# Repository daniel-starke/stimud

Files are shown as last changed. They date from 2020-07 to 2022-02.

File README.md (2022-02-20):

STIMUD
======

The **Sti**ck **Mu**lti **D**rive makes it possible to host multiple bootable USB images in one device.  
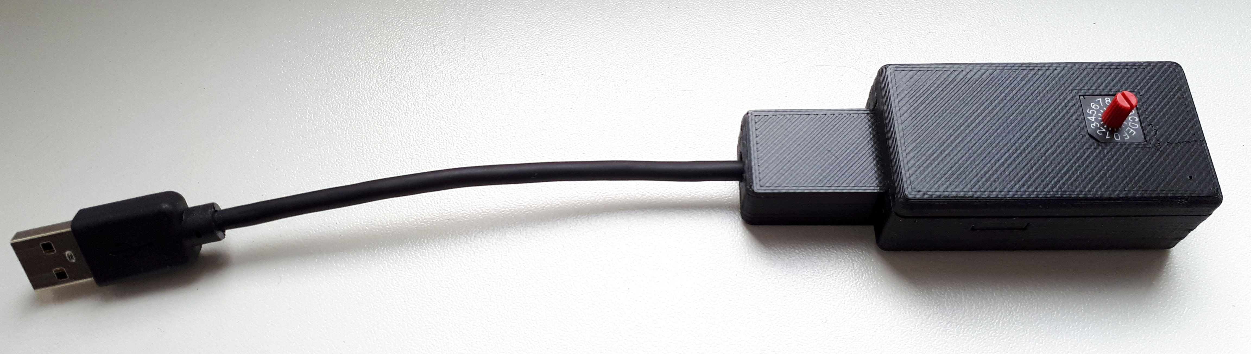
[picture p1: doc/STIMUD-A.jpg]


Features
========

- small and cheap design
- up to 16 different USB images in one device
- flexible storage capacity options by using standard microSD cards as backbone
- moderate speed: 6.36 MByte/s write, 17.2 MByte/s read ([tested](doc/h2testw-stimud.txt) with SanDisk Ultra 16GB)
- fast USB startup time of [~3 seconds](doc/startup-lz4.txt)
- as little as 0.7W energy consumption
- status and activity LED
- supported backbone file systems: FAT32, exFAT, NTFS, ext3 and ext4

Hardware Assembly
=================

STIMUD was made in three revisions. A, B and C. Each required a different level of soldering skills.  
Simple through-hole soldering skill is needed for revision A and C whereas C can be seen as improved version of A.  
Advanced SMD and through-hole soldering skills are needed to assemble revision B. Especially when using a USB-C connector.  

Required Tools
--------------

- soldering iron and lead
- 3D printer
- rasp
- glue
- microSD card reader/writer

Revision A and C
----------------

Needed parts:  
- 1x [LicheePi Zero](https://www.aliexpress.com/item/4000223515312.html)
- 1x [rotary switch with real or complementary code, 10 or 16 positions and a 3:1 or 3:3 footprint](https://lcsc.com/product-detail/Coded-Rotary-Switches_Knitter-switch_DRS4116_Knitter-switch-DRS4116_C237060.html)
- 2x [single row flat pin header with 7 pins](https://www.aliexpress.com/item/32977160718.html)
- 2x [single row flat pin socket with 7 pins](https://www.aliexpress.com/item/32977160718.html)
- 1x [micro USB cable](https://www.aliexpress.com/item/4000540452118.html)
- 1x [microSD card](https://www.aliexpress.com/item/33034672593.html)
- 1x [self adhesive 3mm thick foam pad](https://www.aliexpress.com/item/4000450236527.html)
- 1x [STIMUD PCB Rev. A](hw/switch-a/gerber) or 1x [STIMUD PCB Rev. C](hw/switch-c/gerber)
- 1x [STIMUD case](hw/switch-a/Case.FCStd)

The rotary switch and flat pin headers are soldered to the STIMUD PCB. See KiCAD project for [rev. A](hw/switch-a/switch.pro) or [rev. C](hw/switch-c/switch.pro).  
Gerber files for manufacturing at JLCPCB are provided [here](hw/switch-a/gerber) for rev. A and [here](hw/switch-c/gerber) for rev. C.  
Be sure to select 1.6mm PCB thickness or adjust the case dimensions.  
Also solder the flat pin sockets to the LicheePi Zero.  
The housing can be 3D printed via a FDM 3D printer. The needed STL files are found [here](hw/switch-a) for both revisions.  
Adjust the tolerance parameters in the [FreeCAD project](hw/switch-a/Case.FCStd) to match the used 3D printer performance.  
This step requires re-creation of the STL files for 3D printing. It is recommended to use the Mesh Design workspace in FreeCAD to adjust the quality settings before STL export.  
Be sure to print `CaseB.stl` and `ConA.stl` with support material. Some parts may need to be rasped for a proper fit afterwards.

Assembly example:  
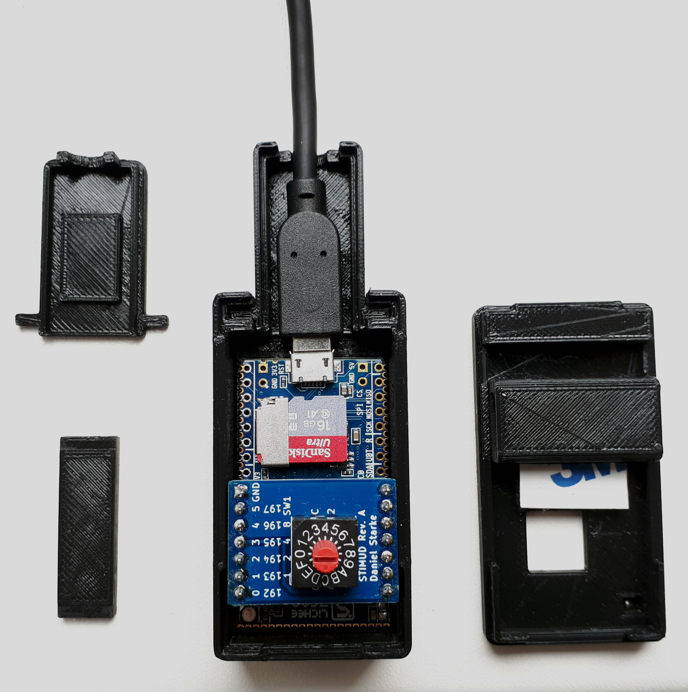
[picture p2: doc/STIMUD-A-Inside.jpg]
  
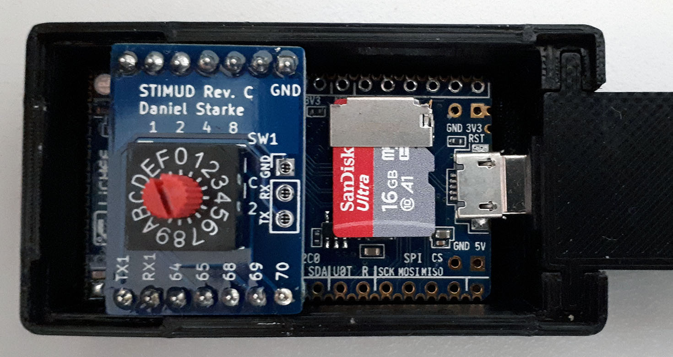
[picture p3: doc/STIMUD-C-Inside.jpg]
  


Add some glue between ConA part and USB cable for pull relief.  
It may needs a little hole for the LED light in CaseB if the used case material transparency is insufficient.  
Revision C fixes the issue in revision A, that the LED shared the same pins as the rotary switch and also adds a serial console pin header.  

**It is highly recommended to use rev. C instead of rev. A.**

Note that the serial console function for rev. C is not yet implemented.

Revision B
----------

Needed parts:  
- 1x [LicheePi Zero](https://www.aliexpress.com/item/4000223515312.html)
- 1x [vertical rotary switch with real or complementary code, 10 or 16 positions and a 4:1 footprint](https://lcsc.com/product-detail/Coded-Rotary-Switches_Knitter-switch_DRR4016_Knitter-switch-DRR4016_C237044.html)
- 2x [single row pin header with 30 pins and 1.27mm spacing](https://lcsc.com/product-detail/Pin-Header-Female-Header_BOOMELE-Boom-Precision-Elec-1-27mm-1x50P_C3408.html)
- 1x [single row pin header with 3 pins and 2.54mm spacing](https://lcsc.com/product-detail/Pin-Header-Female-Header_BOOMELE-Boom-Precision-Elec-C49257_C49257.html) (optional)
- 1x [USB-A plug](https://lcsc.com/product-detail/USB-Connectors_Jing-Extension-of-the-Electronic-Co-C9739_C9739.html) or [USB-C receptacle](https://lcsc.com/product-detail/USB-Connectors_Korean-Hroparts-Elec-TYPE-C-31-M-12_C165948.html)
- 1x [microSD card socket](https://lcsc.com/product-detail/Card-Sockets-Connectors_Korean-Hroparts-Elec-TF-01A_C91145.html)
- 1x [microSD card](https://www.aliexpress.com/item/33034672593.html)
- 2x [5.1kOhm 0603 SMD resistor](https://lcsc.com/product-detail/Chip-Resistor-Surface-Mount_UNI-ROYAL-Uniroyal-Elec-0603WAF5101T5E_C23186.html) (only in case of USB-C receptacle)
- 1x [33kOhm 0603 SMD resistor](https://lcsc.com/product-detail/Chip-Resistor-Surface-Mount_UNI-ROYAL-Uniroyal-Elec-0603WAF3302T5E_C4216.html)
- 6x [100nF 0603 SMD capacitor](https://lcsc.com/product-detail/Multilayer-Ceramic-Capacitors-MLCC-SMD-SMT_IHHEC-HOLY-STONE-ENTERPRISE-CO-LTD-C0603X104K050T_C187860.html)
- 1x [self adhesive 3mm thick foam pad](https://www.aliexpress.com/item/4000450236527.html)
- 3x [M3 nut](https://www.aliexpress.com/item/32981886856.html)
- 3x [12mm M3 screw](https://www.aliexpress.com/item/32981886856.html)
- 1x [STIMUD PCB Rev. B](hw/switch-b/gerber)
- 1x [STIMUD case](hw/switch-b/Case.FCStd)

The rotary switch, pin headers, microSD card socket, USB connector, SMD resistors and capacitors are soldered to the STIMUD PCB. The 5.1kOhm resistors are only needed for
the variant with the USB-C receptacle. See KiCAD project for [rev. B](hw/switch-b/switch.pro).  
Gerber files for manufacturing at JLCPCB are provided [here](hw/switch-b/gerber).  
Be sure to select 1.2mm PCB thickness or adjust the case dimensions.  
The LicheePi Zero is soldered directly to the pin headers previously soldered to the STIMUD PCB. Be sure to finish soldering the capacitors before attaching the LicheePi Zero.  
The housing can be 3D printed via a FDM 3D printer. The needed STL files are found [here](hw/switch-b) for the USB-A variant.  
Adjust the tolerance parameters in the [FreeCAD project](hw/switch-b/Case.FCStd) to match the used 3D printer performance.  
This step requires re-creation of the STL files for 3D printing. It is recommended to use the Mesh Design workspace in FreeCAD to adjust the quality settings before STL export.  
Everything can be printed without support material.

Assembly example:  
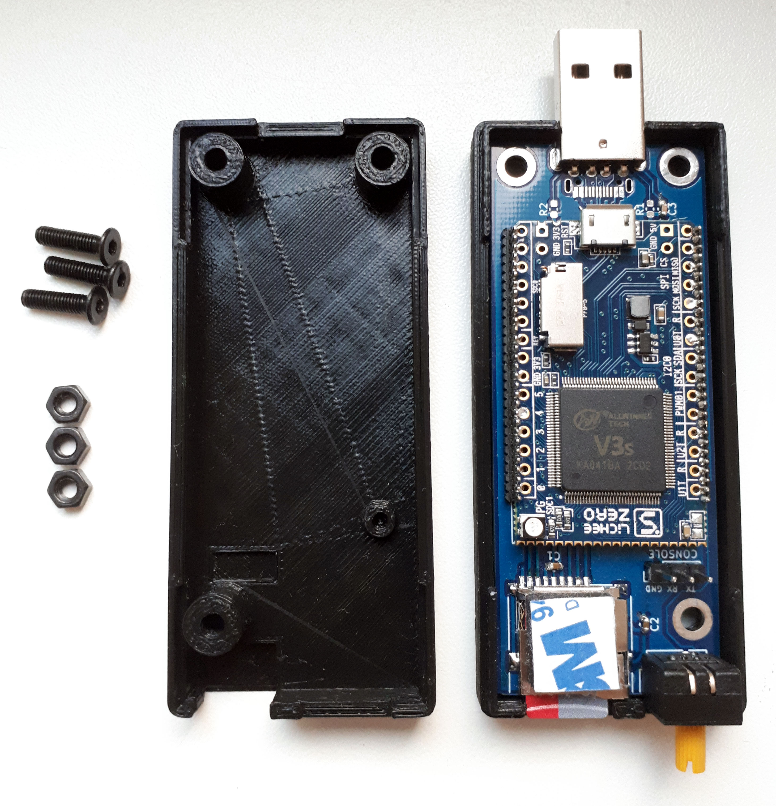
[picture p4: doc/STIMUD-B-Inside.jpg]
  
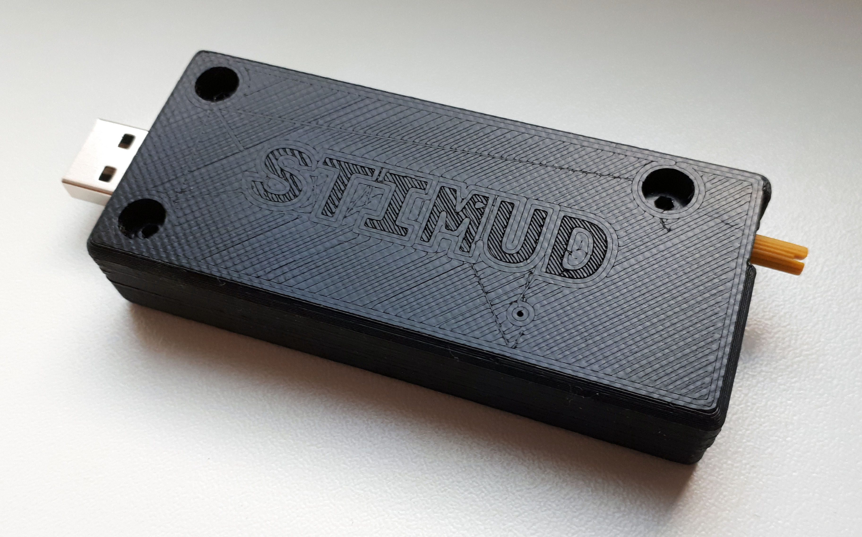
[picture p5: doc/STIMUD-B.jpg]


Attach the self adhesive foam pad on the microSD card socket to avoid unaligned insertions of microSD cards.

Note that there exists no housing for the USB-C receptacle variant yet.

**Important: Never operate the STIMUD REV B with two microSD cards at the same time! This will damage the cards and the LicheePi Zero board.**

Software Setup
==============

Build Pre-requirements
----------------------

The initial boot image can be build in Linux using the provided `build.sh` script.  
For the pre-requirements see https://buildroot.org/downloads/manual/manual.html#requirement

Build Boot Image
----------------

Execute `build.sh`. The resulting image can be found in `build/output/images/`. Additional flags can be passed to `build.sh` to control the build output.  
Use dd on Linux or [Rufus](https://rufus.ie/) on Windows to flash the microSD card.  
The partition for the sub images will be created automatically by STIMUD according to `stimud.cfg` after first start, which may take a bit longer.  
A pre-compiled image is also provided.

Configuration
-------------

Set the rotary switch to position **`F`** and adjust `stimud.cfg`.  
You can change the properties of the rotary switch coding, preferred backbone filesystem and image configurations here.  
Note that the backbone filesystem option is only used for initial format. Any of the supported filesystems can be used.  
Images can be copied as image files or created for example with the following Linux command:  

```shell
for i in 0 1 2 3 4 5 6 7 8 9 A B C D E; do dd if=/dev/zero of=$i.img bs=1048576 count=1008; mkfs -t vfat -n $i $i.img; done
```

This creates the images 0.img, 1.img, 2.img, 3.img, 4.img, 5.img, 6.img, 7.img, 8.img, 9.img, A.img, B.img, C.img, D.img and E.img in the current directory with a size of 1018MB each formatted with FAT32.  
Note that the configuration file `stimud.cfg` can be located in three locations:

1. secondary partition on the microSD card (which also includes the images)
2. primary partition on the microSD card
3. Linux kernel initfs

The priority is handled in the order given above. A missing file is replaced by the next location in the list.

Usage
=====

After successful configuration, set the rotary switch to the desired position before plugging it to the host.  
The current image can be changed at any time and will be effective on next connection to the host.  
Each image file represents a full USB storage drive image.  
Usually one position remains reserved to access the STIMUD configuration. This is position `F` by default.

Access to the internal command-line console is provided in STIMUD rev. B and C via a 3.3V TTL UART connection
with 115200 Baud, 8 data bits, no parity and 1 stop bit. The STIMUD related files are stored there in `/root`.
[Such](https://www.aliexpress.com/item/32617951363.html) an FT232R adapter module can be used for example, to connect a PC to it.

**Important: Never operate the STIMUD REV B with two microSD cards at the same time! This will damage the cards and the LicheePi Zero board.**

LED States
==========

|LED |State |Meaning
|:---:|---|---
|ES| green blinking |starting
|E0| blue blinking |disk activity after successful startup
|E2| red blinking |script error (check `stimud.sh`)
|E1| red/blue alternating |configuration error (check `stimud.cfg`)
|Ex| red always on |unknown error

Note that the LEDs in revision A are also connected to the rotary switch. Set it to position `0` or
`F` depending on whether the switch uses real or complementary code to see all LEDs. Other positions
may disable all or some LEDs. Revision C fixes this issue by using different pins for the rotary switch.

Files
=====

|Name |Meaning
|---|---
|build.sh |Shell script to build the STIMUD SD card images.
|board/boot.cmd |U-Boot boot script.
|board/genimage.cfg |Linux kernel specific image generation configuration.
|board/stimud.dts |U-Boot specific device tree reference.
|configs/buildroot.config |Buildroot specific build configuration.
|configs/busybox-fragments.config |Busybox specific build configuration fragments.
|configs/linux.config |Linux kernel specific build configuration.
|configs/uboot.config |U-Boot specific build configuration.
|src/start.sh |Script loaded at STIMUD start-up.
|src/stimud.cfg |STIMUD configuration template.
|src/stimud.sh |Script with the actual STIMUD function.
|src/stimud-gpio.c |Application to control the Allwinner V3s GPIOs.

License
=======

See [copying file](doc/COPYING).  

Contributions
=============

No content contributions are accepted. Please file a bug report or feature request instead.  
This decision was made in consideration of the used license.

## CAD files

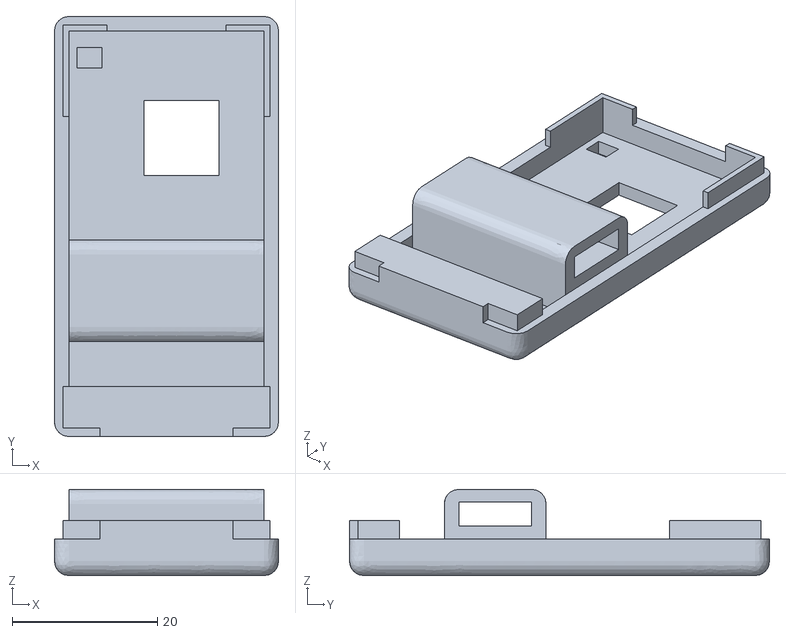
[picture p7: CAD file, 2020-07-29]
hw/switch-a/CaseB.stl
30.8 x 57.8 x 11.8

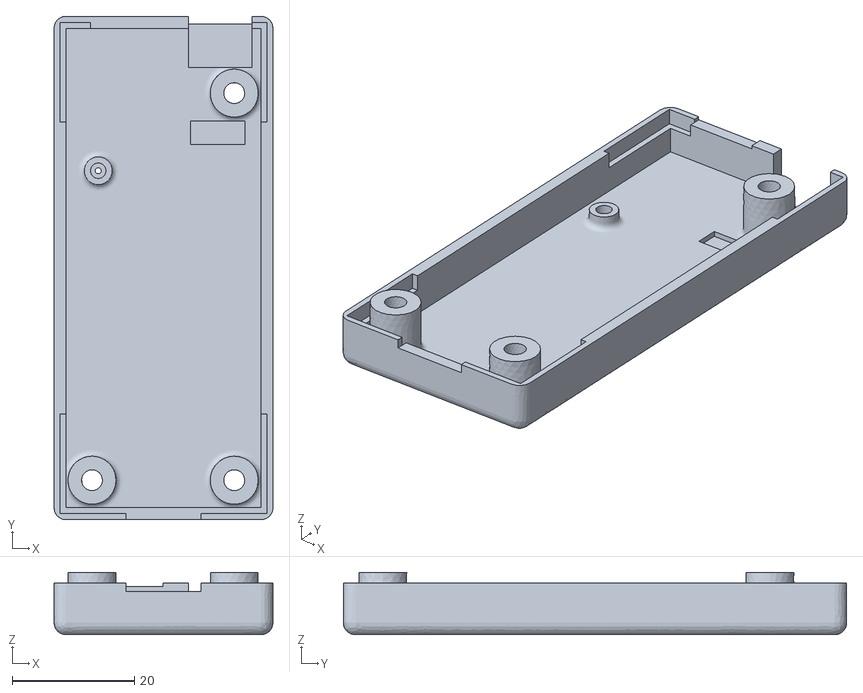
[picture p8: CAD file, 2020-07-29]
hw/switch-b/CaseB.stl
35.8 x 82.3 x 10.2

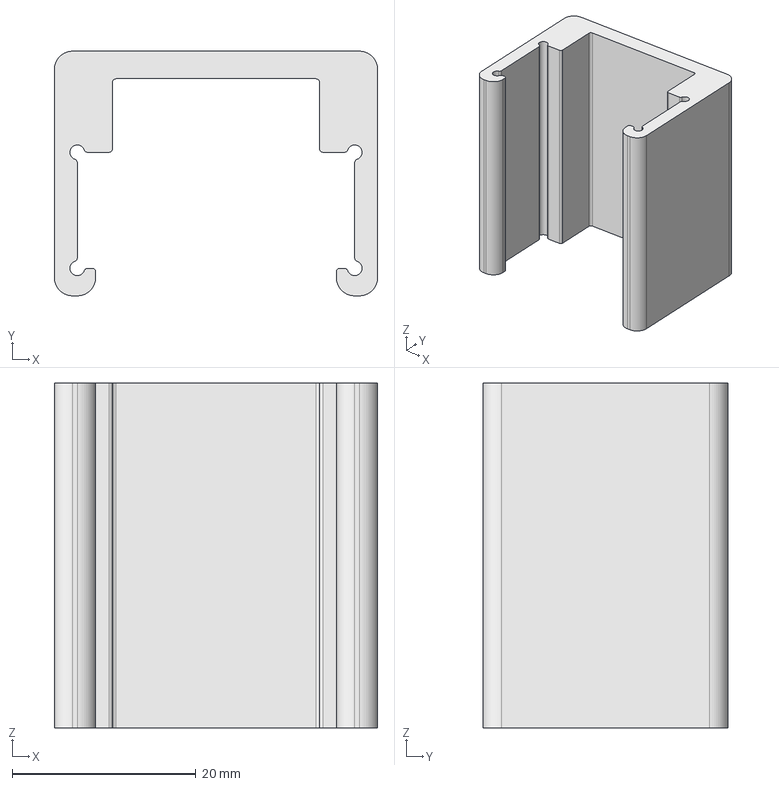
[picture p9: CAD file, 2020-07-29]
hw/testbench/clip.FCStd
35.1 x 26.6 x 37.5 mm

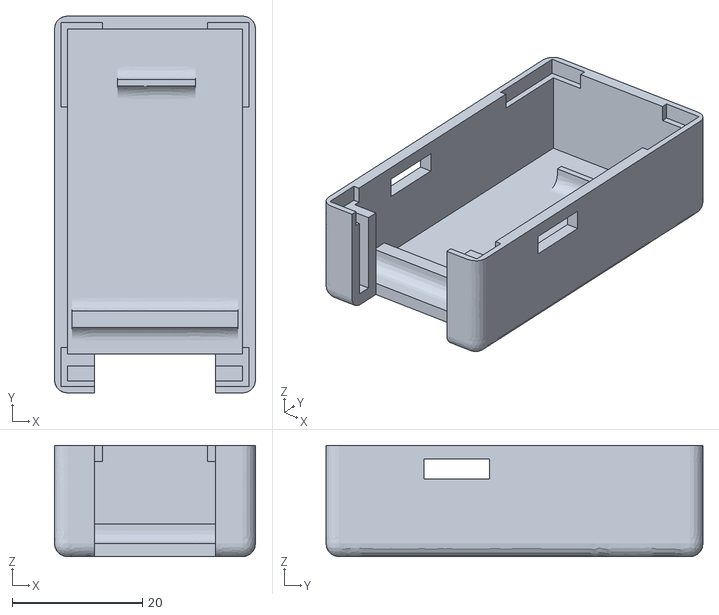
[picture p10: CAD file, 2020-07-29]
hw/switch-a/CaseA.stl
30.8 x 57.8 x 17.1

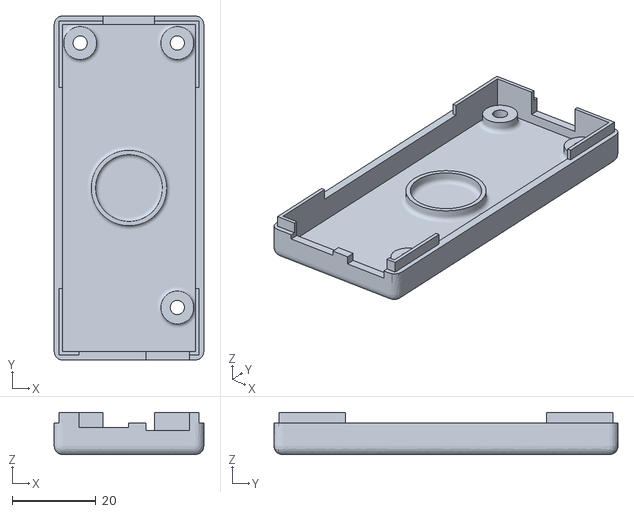
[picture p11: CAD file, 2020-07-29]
hw/switch-b/CaseA.stl
35.8 x 82.3 x 10.1

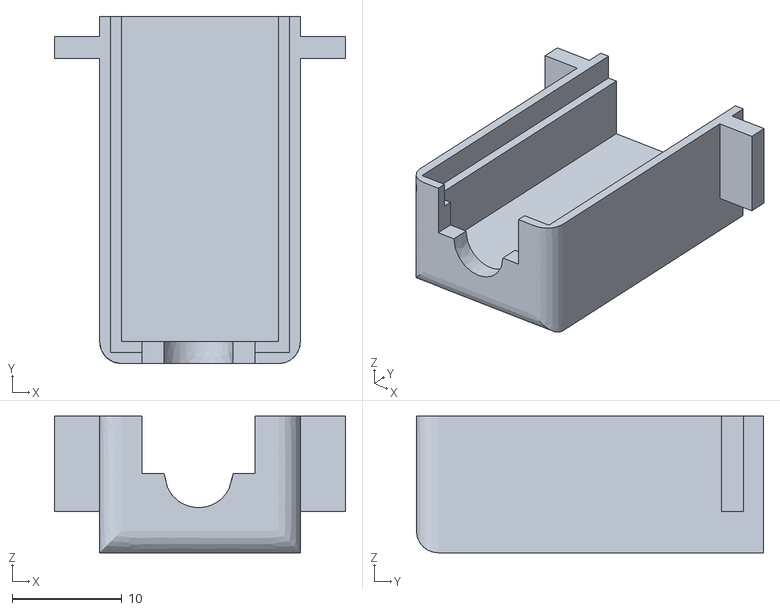
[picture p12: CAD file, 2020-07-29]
hw/switch-a/ConA.stl
26.5 x 31.6 x 12.5

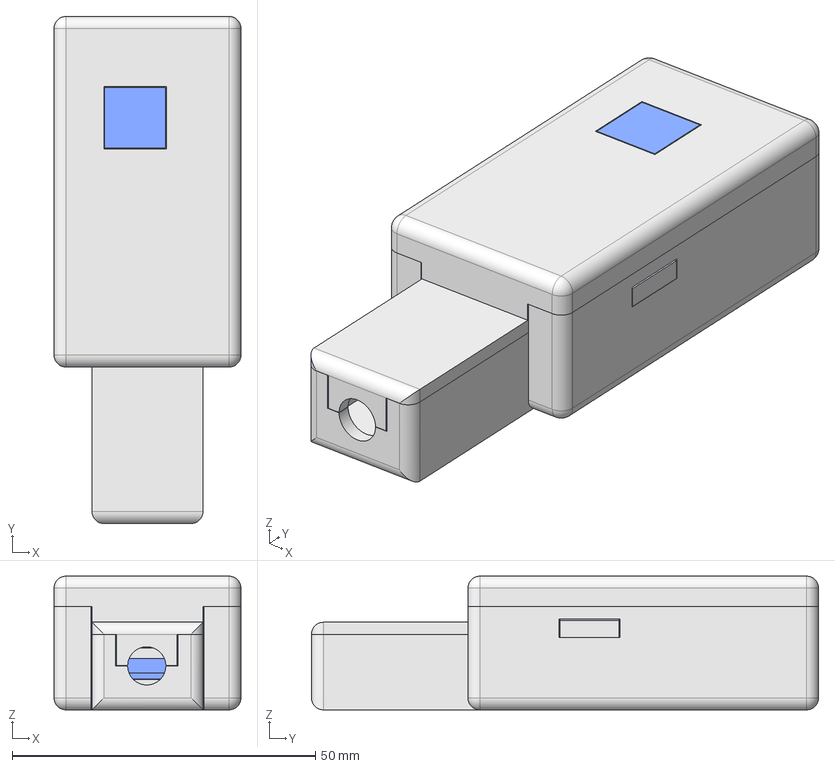
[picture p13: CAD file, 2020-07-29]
hw/switch-a/Case.FCStd
30.8 x 83.6 x 22.1 mm
Board
CaseA
CaseB
ConA
ConB
Bolt

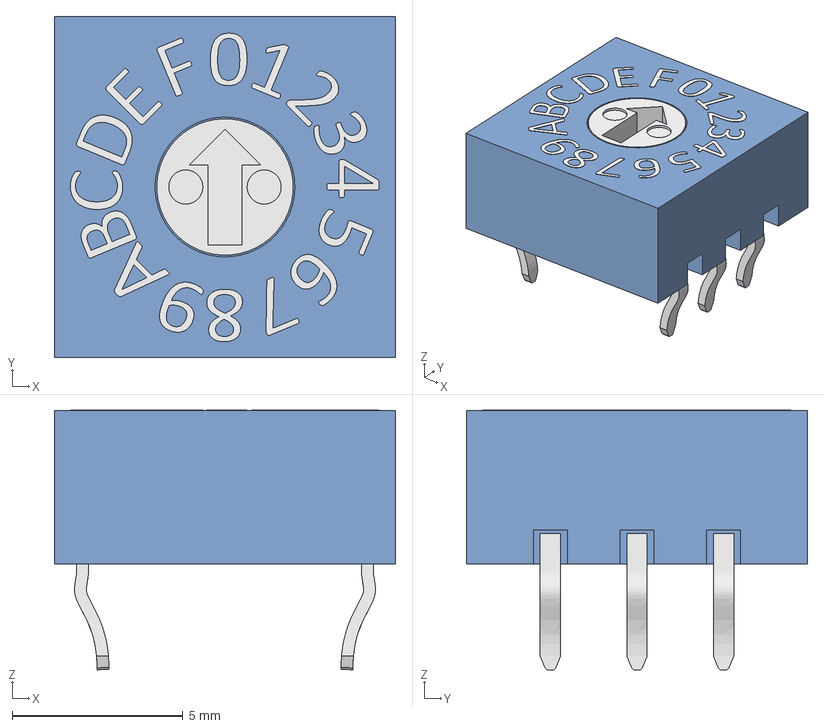
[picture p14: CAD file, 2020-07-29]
hw/switch-a/8421C.step
10.0 x 10.0 x 7.61 mm

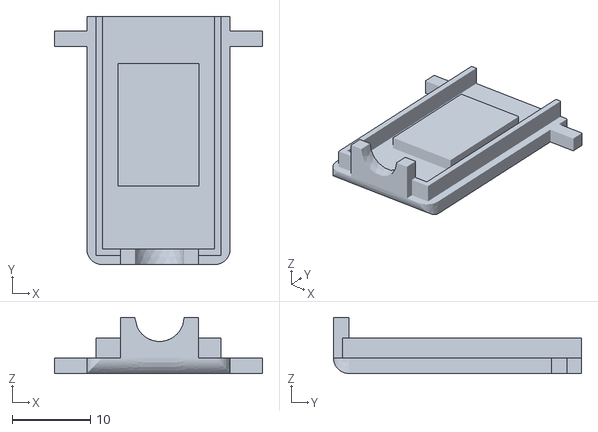
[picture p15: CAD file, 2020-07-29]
hw/switch-a/ConB.stl
26.5 x 31.6 x 7.15

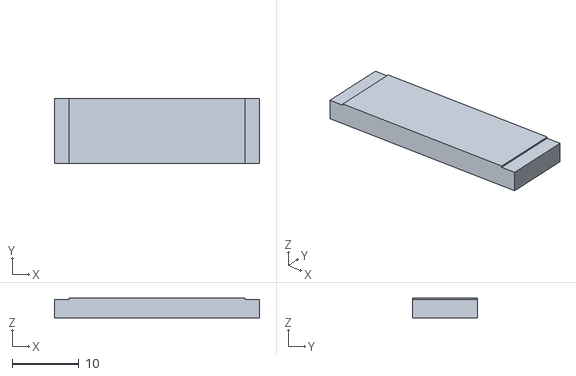
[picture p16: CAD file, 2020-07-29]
hw/switch-a/Bolt.stl
30.8 x 9.70 x 3.00

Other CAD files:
hw/switch-a/8421C.FCStd

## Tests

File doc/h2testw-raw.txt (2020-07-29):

Writing:
15177 MByte
14:10 min
17.8 MByte/s

Reading:
15177 MByte
7:43 min
32.7 MByte/s

Test finished without errors.
You can now delete the test files *.h2w or verify them again.
Writing speed: 17.8 MByte/s
Reading speed: 32.7 MByte/s
H2testw v1.4

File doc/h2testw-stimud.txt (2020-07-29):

Writing:
15169 MByte
39:44 min
6.36 MByte/s

Reading:
15169 MByte
14:42 min
17.2 MByte/s

Test finished without errors.
You can now delete the test files *.h2w or verify them again.
Writing speed: 6.36 MByte/s
Reading speed: 17.2 MByte/s
H2testw v1.4

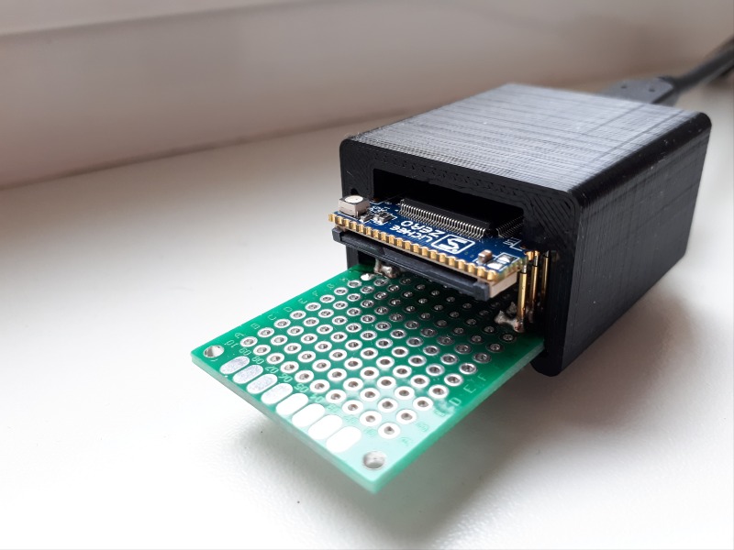
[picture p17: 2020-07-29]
hw/testbench/example-top.jpg

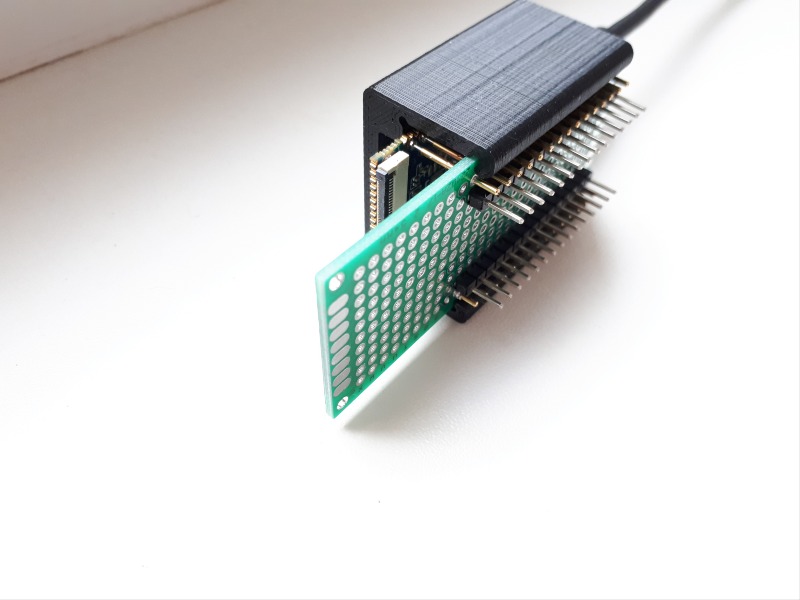
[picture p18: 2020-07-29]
hw/testbench/example-bottom.jpg

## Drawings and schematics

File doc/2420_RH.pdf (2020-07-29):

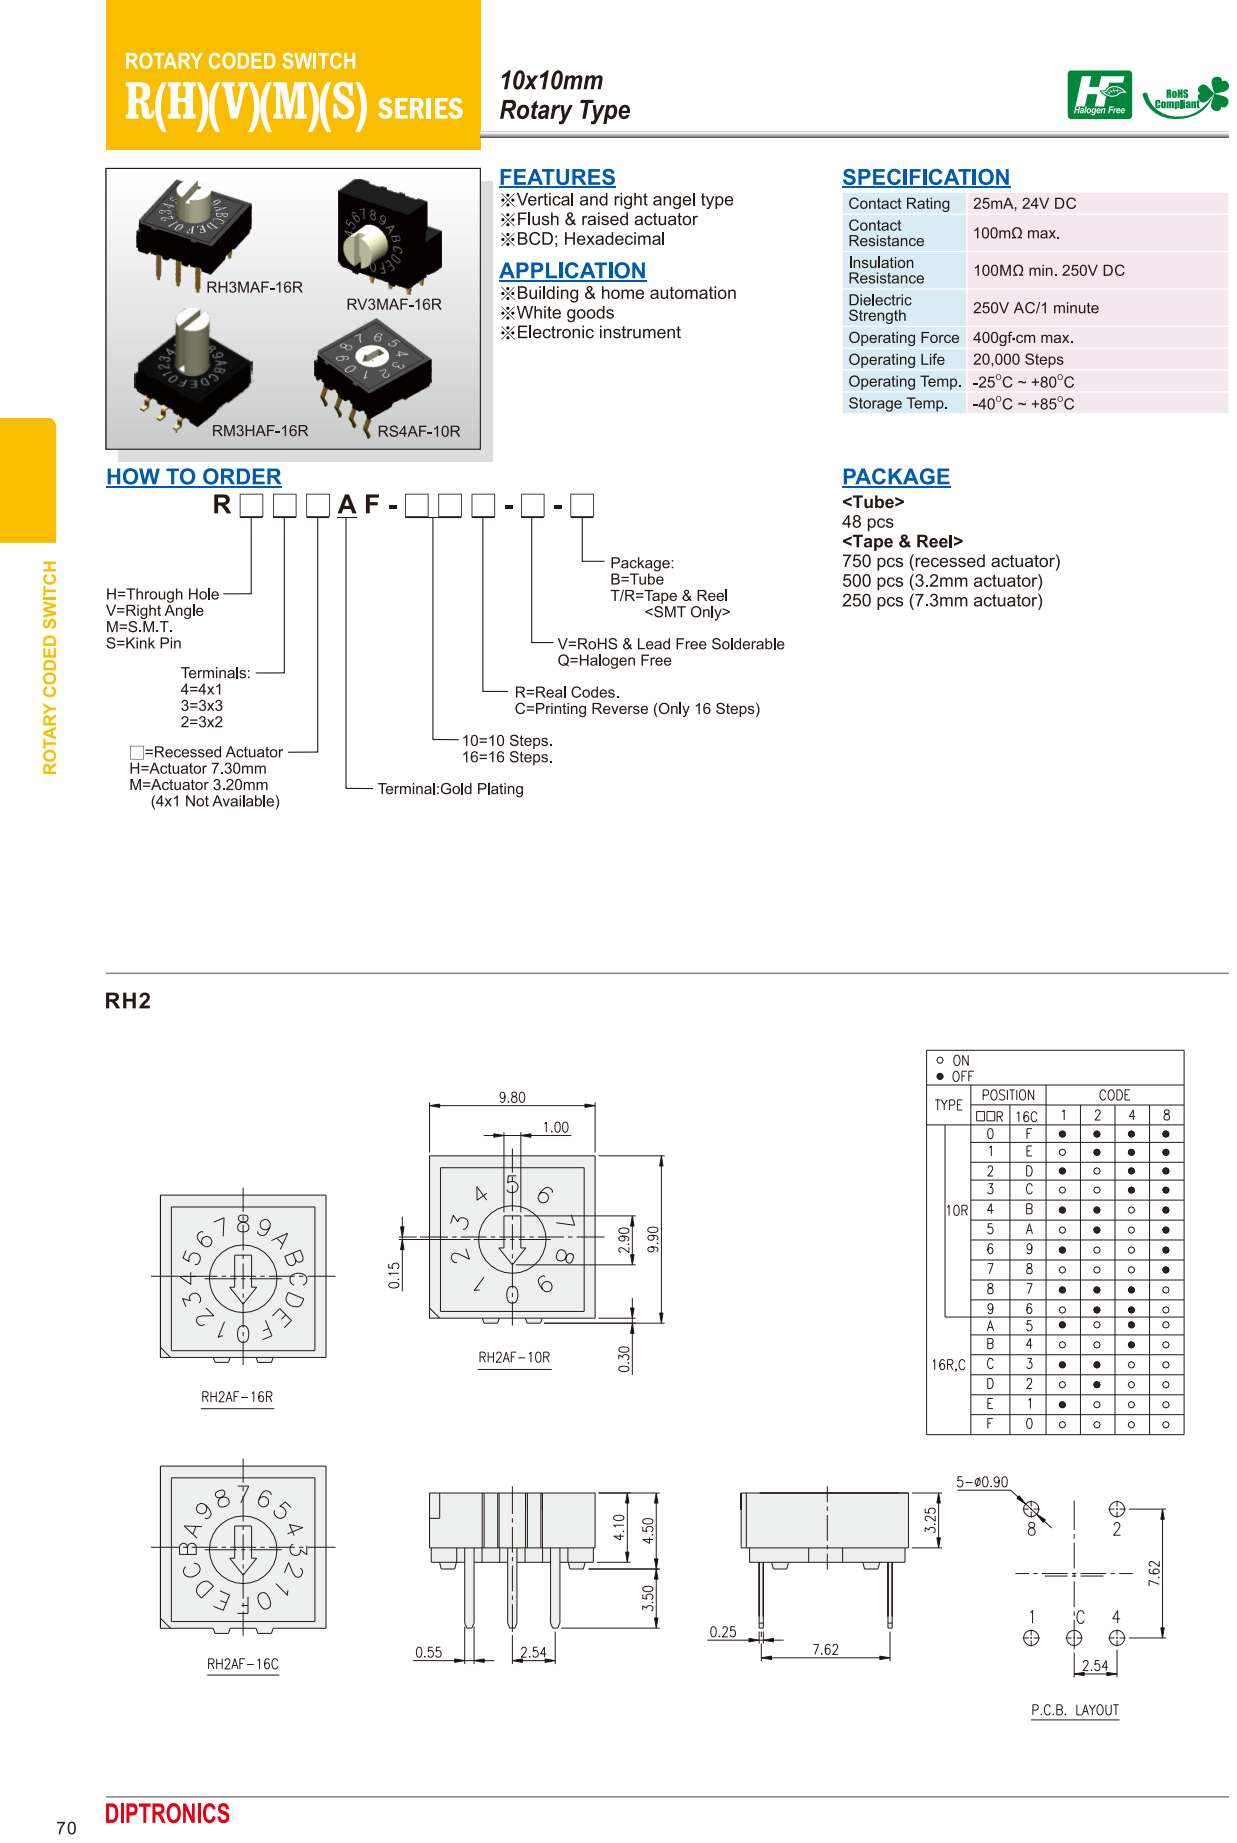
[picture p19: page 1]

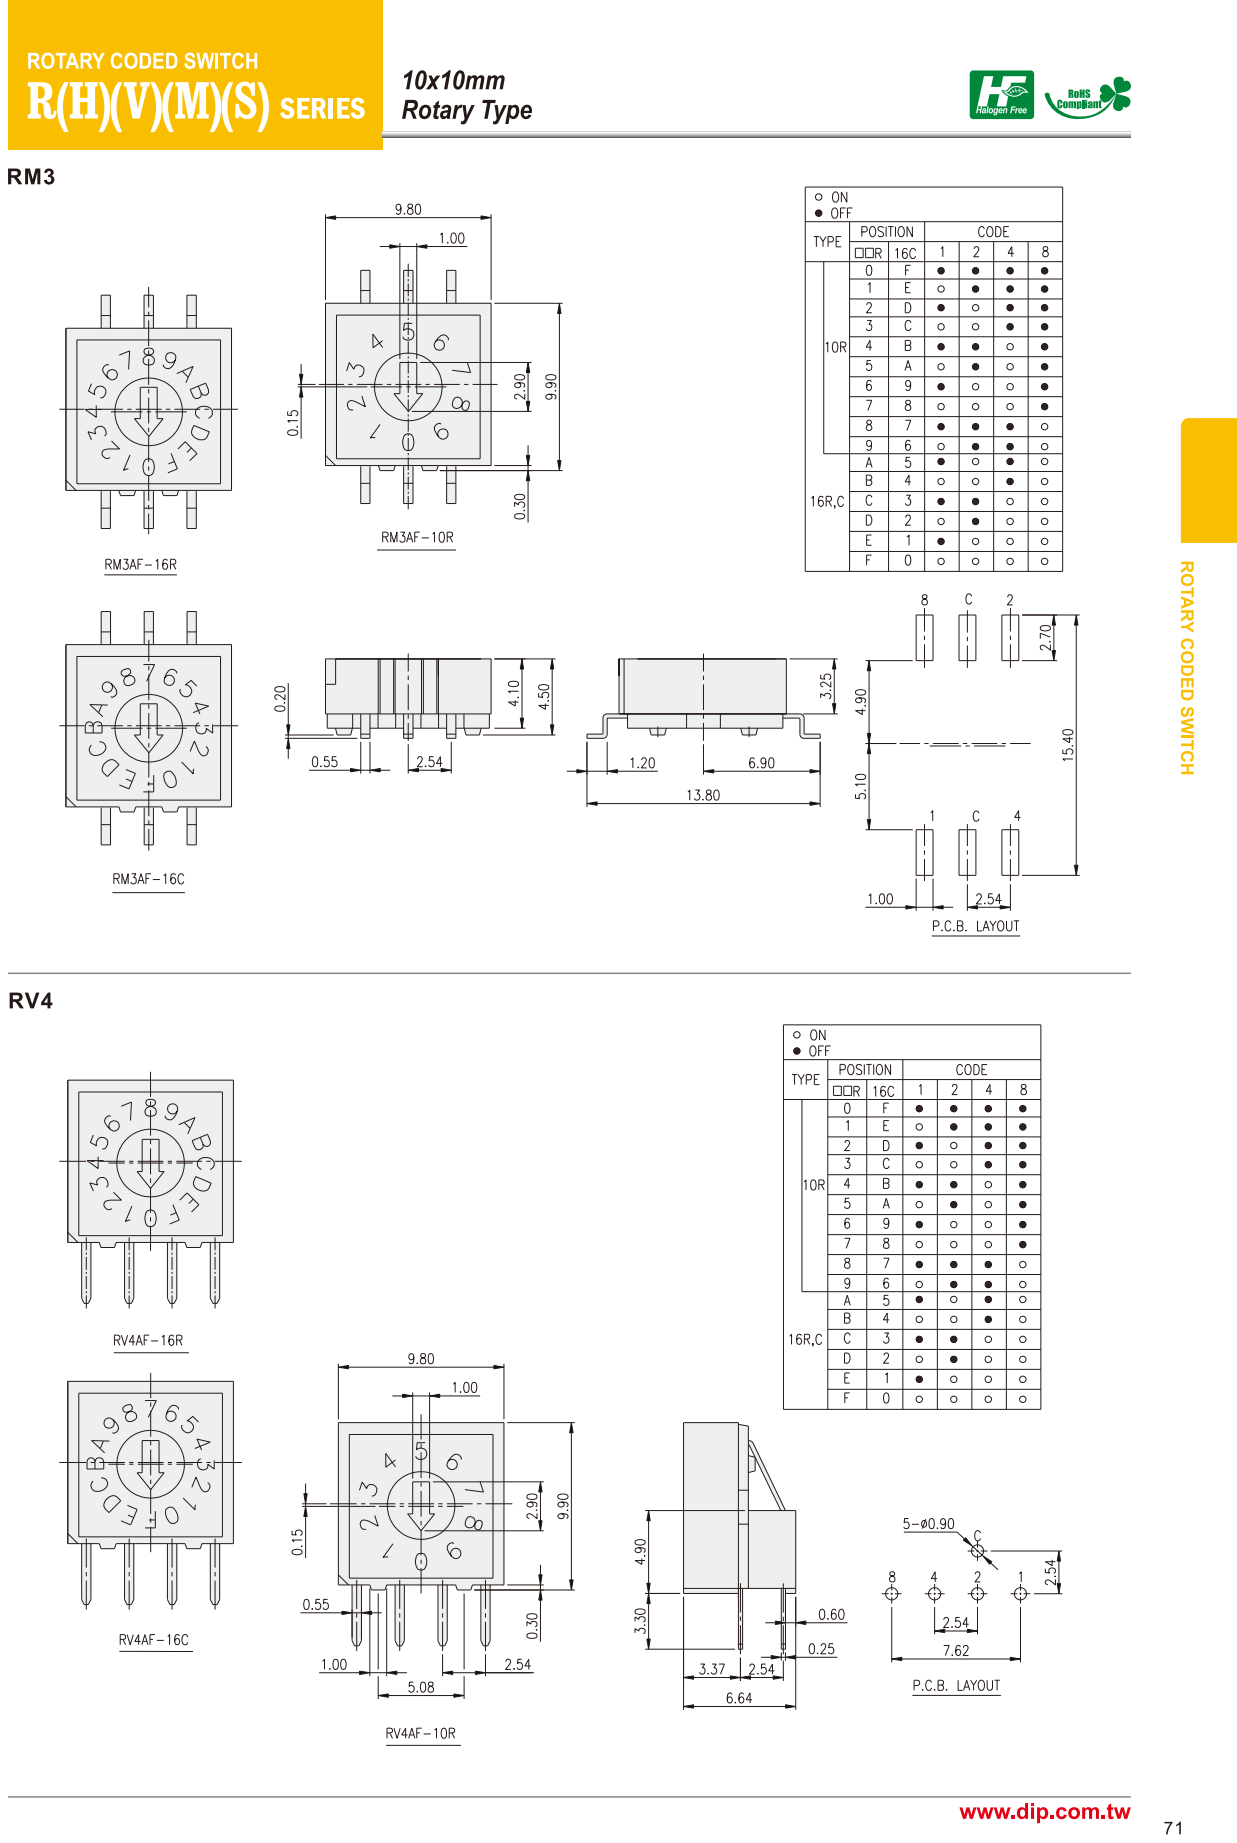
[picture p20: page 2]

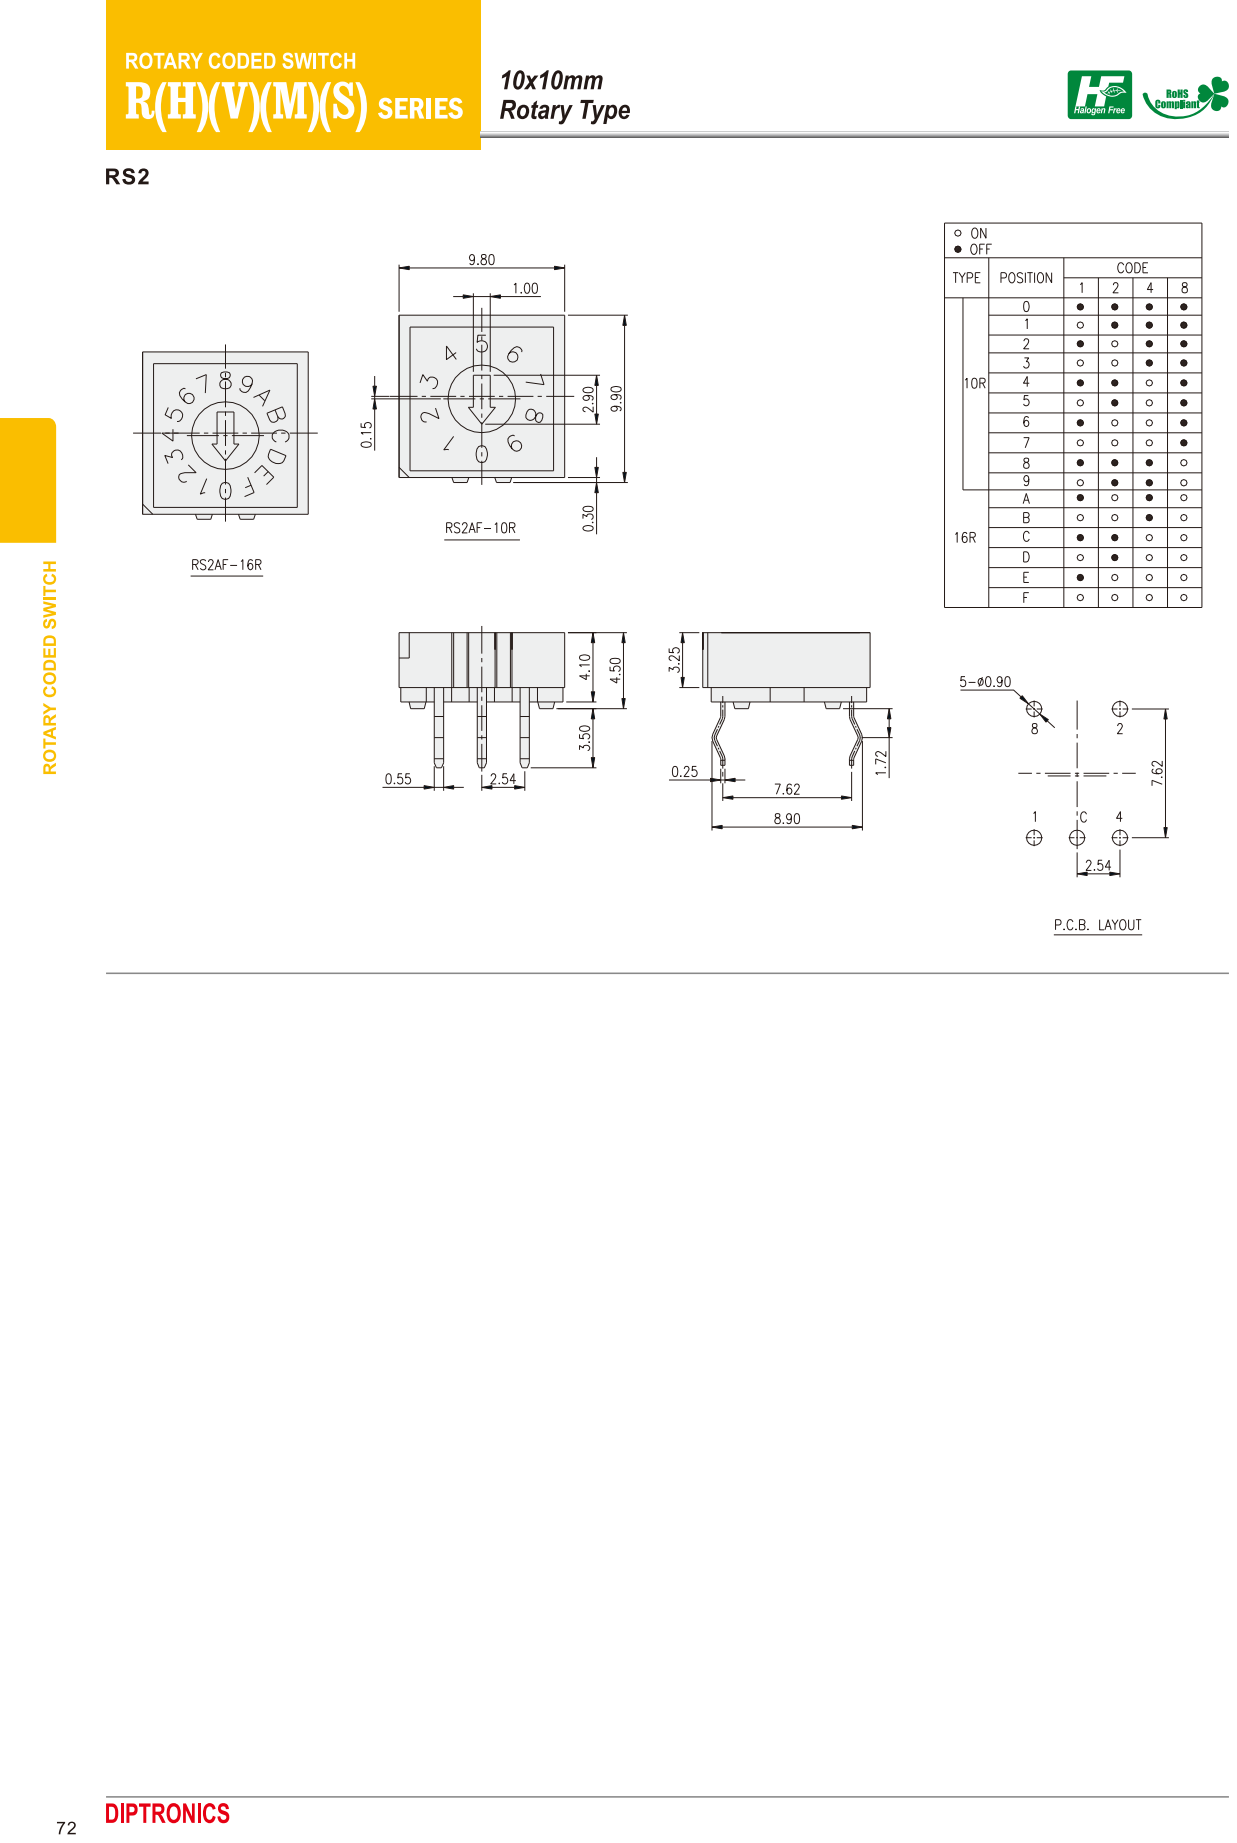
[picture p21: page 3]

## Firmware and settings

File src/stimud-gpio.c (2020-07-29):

/**
 * @file stimud-gpio.c
 * @author Daniel Starke
 * @copyright Copyright 2020 Daniel Starke
 * @date 2020-04-01
 * @version 2020-04-11
 * 
 * @remarks This code is Allwinner V3s specific.
 */
#include <errno.h>
#include <fcntl.h>
#include <stdlib.h>
#include <stdio.h>
#include <stdint.h>
#include <string.h>
#include <sys/mman.h>
#include <sys/stat.h>
#include <sys/types.h>
#include <unistd.h>


/* Defines the memory regions for the GPIO port registers. Code changes are necessary if these
 * values are changed. */
#define GPIO_PORT_BASE 0x01C20800UL
#define GPIO_PORT_SIZE 0x24
#define GPIO_PORT_COUNT 7
#define GPIO_PORT_NUMS 32 /* same as in Linux for compatibility */


/** Defines the file descriptor for standard outputs.  */
#define FOUT stdout


/**
 * @def likely(x) 
 * Optimizes branch prediction for the case that the expression evaluates to true.
 * @def unlikely(x) 
 * Optimizes branch prediction for the case that the expression evaluates to false.
 * @def unreachable()
 * Let the compiler assume that this code path cannot be taken.
 */
#if defined(__GNUC__) || defined(__clang__)
#define likely(x) __builtin_expect(!!(x), 1)
#define unlikely(x) __builtin_expect(!!(x), 0)
#define unreachable() __builtin_unreachable()
#else
#define likely(x) (x)
#define unlikely(x) (x)
#define unreachable()
#endif


/**
 * Describes the port controller registers of a single port.
 */
typedef struct {
	uint32_t CFG[4];
	uint32_t DAT;
	uint32_t DRV[2];
	uint32_t PUL[2];
} tGpioPort;


/**
 * Prints description for a register.
 */
typedef struct {
	const char * key;
	uint32_t reg;
	size_t offset;
	size_t size;
	void (*printer)(FILE * fd, const uint32_t val, const char * user);
	const char * user;
} tPrintDesc;


/**
 * Number of available IOs per GPIO port.
 */
static const size_t ioCount[] = {
	0, 10, 4, 0, 25, 7, 6
};


/**
 * List of available functions per IO pin.
 * 
 * @remarks See Allwinner V3s Datasheet v1.0 chapter 3.2.
 */
static const char * ioFn[] = {
	/* PA */
	NULL, NULL, NULL, NULL, NULL, NULL, NULL, NULL, NULL, NULL, NULL, NULL, NULL, NULL, NULL, NULL, NULL, NULL, NULL, NULL, NULL, NULL, NULL, NULL, NULL, NULL, NULL, NULL, NULL, NULL, NULL, NULL,
	/* PB */
	"UART2_TX\0\0\0\0PB_EINT0",
	"UART2_RX\0\0\0\0PB_EINT1",
	"UART2_RTS\0\0\0\0PB_EINT2",
	"UART2_CTS\0\0\0\0PB_EINT3",
	"PWM0\0\0\0\0PB_EINT4",
	"PWM1\0\0\0\0PB_EINT5",
	"TWI0_SCK\0\0\0\0PB_EINT6",
	"TWI0_SDA\0\0\0\0PB_EINT7",
	"TWI1_SCK\0UART0_TX\0\0\0PB_EINT8",
	"TWI1_SDA\0UART0_RX\0\0\0PB_EINT8",
	NULL, NULL, NULL, NULL, NULL, NULL, NULL, NULL, NULL, NULL, NULL, NULL, NULL, NULL, NULL, NULL, NULL, NULL, NULL, NULL, NULL, NULL,
	/* PC */
	"SDC2_CLK\0SPI0_MISO\0\0\0",
	"SDC2_CMD\0SPI0_CLK\0\0\0",
	"SDC2_RST\0SPI0_CS\0\0\0",
	"SDC2_D0\0SPI0_MOSI\0\0\0",
	NULL, NULL, NULL, NULL, NULL, NULL, NULL, NULL, NULL, NULL, NULL, NULL, NULL, NULL, NULL, NULL, NULL, NULL, NULL, NULL, NULL, NULL, NULL, NULL, NULL, NULL, NULL, NULL,
	/* PD */
	NULL, NULL, NULL, NULL, NULL, NULL, NULL, NULL, NULL, NULL, NULL, NULL, NULL, NULL, NULL, NULL, NULL, NULL, NULL, NULL, NULL, NULL, NULL, NULL, NULL, NULL, NULL, NULL, NULL, NULL, NULL, NULL,
	/* PE */
	"CSI_PCLK\0LCD_CLK\0\0\0",
	"CSI_MCLK\0LCD_DE\0\0\0",
	"CSI_HSYNC\0LCD_HSYNC\0\0\0",
	"CSI_VSYNC\0LCD_VSYNC\0\0\0",
	"CSI_D0\0LCD_D2\0\0\0",
	"CSI_D1\0LCD_D3\0\0\0",
	"CSI_D2\0LCD_D4\0\0\0",
	"CSI_D3\0LCD_D5\0\0\0",
	"CSI_D4\0LCD_D6\0\0\0",
	"CSI_D5\0LCD_D7\0\0\0",
	"CSI_D6\0LCD_D10\0\0\0",
	"CSI_D7\0LCD_D11\0\0\0",
	"CSI_D8\0LCD_D12\0\0\0",
	"CSI_D9\0LCD_D13\0\0\0",
	"CSI_D10\0LCD_D14\0\0\0",
	"CSI_D11\0LCD_D15\0\0\0",
	"CSI_D12\0LCD_D18\0\0\0",
	"CSI_D13\0LCD_D19\0\0\0",
	"CSI_D14\0LCD_D20\0\0\0",
	"CSI_D15\0LCD_D21\0\0\0",
	"CSI_FIELD\0CSI_MIPI_MCLK\0\0\0",
	"CSI_SCK\0TWI1_SCK\0UART1_TX\0\0",
	"CSI_SDA\0TWI1_SDA\0UART1_RX\0\0",
	"\0LCD_D22\0UART1_RTS\0\0",
	"\0LCD_D23\0UART1_CTS\0\0",
	NULL, NULL, NULL, NULL, NULL, NULL, NULL,
	/* PF */
	"SDC0_D1\0JTAG_MS\0\0\0",
	"SDC0_D0\0JTAG_DI\0\0\0",
	"SDC0_CLK\0UART0_TX\0\0\0",
	"SDC0_CMD\0JTAG_DO\0\0\0",
	"SDC0_D3\0UART0_RX\0\0\0",
	"SDC0_D2\0JTAG_CK\0\0\0",
	"\0\0\0\0",
	NULL, NULL, NULL, NULL, NULL, NULL, NULL, NULL, NULL, NULL, NULL, NULL, NULL, NULL, NULL, NULL, NULL, NULL, NULL, NULL, NULL, NULL, NULL, NULL, NULL,
	/* PG */
	"SDC1_CLK\0\0\0\0PG_EINT0",
	"SDC1_CMD\0\0\0\0PG_EINT1",
	"SDC1_D0\0\0\0\0PG_EINT2",
	"SDC1_D1\0\0\0\0PG_EINT3",
	"SDC1_D2\0\0\0\0PG_EINT4",
	"SDC1_D3\0\0\0\0PG_EINT5",
	NULL, NULL, NULL, NULL, NULL, NULL, NULL, NULL, NULL, NULL, NULL, NULL, NULL, NULL, NULL, NULL, NULL, NULL, NULL, NULL, NULL, NULL, NULL, NULL, NULL, NULL
};


/**
 * Checks if the given pin number is valid.
 * 
 * @param[in] pin - pin to check
 * @return 1 if the pin was valid, else 0
 */
static int isValidPin(const size_t pin) {
	const size_t port = pin / GPIO_PORT_NUMS;
	if (unlikely(port >= GPIO_PORT_COUNT)) return 0;
	const size_t num = pin % GPIO_PORT_NUMS;
	if (num >= ioCount[port]) return 0;
	return 1;
}


/**
 * Returns the bits starting at the given address, bit offset and
 * with the passed number of bits.
 * 
 * @param[in] addr - pointer to the register
 * @param[in] offset - bit offset within the register
 * @param[in] size - number of bits
 * @return extracted bits
 */
static uint32_t getBits(const volatile uint32_t * addr, size_t offset, size_t size) {
	if (addr == NULL) unreachable();
	if (unlikely(size == 32)) return *addr;
	const uint32_t mask = UINT32_MAX >> (32 - size);
	return (*addr >> offset) & mask;
}


/**
 * Sets the passed bits value at the given address, bit offset and
 * with the number of bits given.
 * 
 * @param[in,out] addr - pointer to the register
 * @param[in] offset - bit offset within the register
 * @param[in] size - number of bits
 * @param[in] val - value to set
 * @remarks val shall not exceed the bit size give or the behavior is undefined.
 */
static void setBits(volatile uint32_t * addr, size_t offset, size_t size, uint32_t val) {
	if (addr == NULL) unreachable();
	if (unlikely(size == 32)) {
		*addr = val;
	} else {
		val <<= offset;
		const uint32_t mask = ~((UINT32_MAX >> (32 - size)) << offset);
		*addr &= mask; /* clear bits */
		*addr |= val; /* set bits */
	}
}


/**
 * Prints the given registers as described to the passed file descriptor.
 * 
 * @param[in,out] fd - output file descriptor
 * @param[in] desc - registers and print description array
 */
static void printRegisters(FILE * fd, const tPrintDesc * desc) {
	const char * fmt[] = {
		"%s = %u 0x%02X b",
		"%s = %u 0x%04X b",
		"%s = %u 0x%06X b",
		"%s = %u 0x%08X b"
	};
	if (fd == NULL || desc == NULL) unreachable();
	for (; desc->key != NULL; desc++) {
		const uint32_t val = getBits(&(desc->reg), desc->offset, desc->size);
		/* print dec, hex */
		fprintf(fd, fmt[desc->size >> 8], desc->key, (unsigned)val, (unsigned)val);
		/* print bin */
		if (desc->size < 1 || desc->size > 32) unreachable();
		uint32_t mask = (uint32_t)1 << (desc->size - 1);
		for (size_t n = 0; n < desc->size; n++, mask >>= 1) {
			fputc((val & mask) != 0 ? '1' : '0', fd);
		}
		/* print mapping */
		if (desc->printer != NULL) {
			fputc(' ', fd);
			(*(desc->printer))(fd, val, desc->user);
		}
		fputc('\n', fd);
	}
}


/**
 * Prints the configuration register pin state.
 * 
 * @param[in] fd - output file descriptor
 * @param[in] val - value of the pin
 * @param[in] user - 0 terminated list of pin functions
 */
static void printCfg(FILE * fd, const uint32_t val, const char * user) {
	const char * fn[8] = {
		"Input", "Output", NULL, NULL, NULL, NULL, NULL, "IO Disabled"
	};
	if (fd == NULL || user == NULL) unreachable();
	for (size_t n = 0; n < 5; n++, user += strlen(user) + 1) {
		fn[n + 2] = (*user == 0) ? "Reserved" : user;
	}
	if (likely(val < 8)) {
		fprintf(fd, "<%s>", fn[val]);
	} else {
		fprintf(fd, "<INVALID>");
	}
}


/**
 * Prints the multi-driving register pin state.
 * 
 * @param[in] fd - output file descriptor
 * @param[in] val - value of the pin
 * @param[in] user - unused
 */
static void printDrv(FILE * fd, const uint32_t val, const char * user) {
	(void)user;
	if (fd == NULL) unreachable();
	if (likely(val < 4)) {
		fprintf(fd, "<Level %u>", (unsigned)val);
	} else {
		fprintf(fd, "<INVALID>");
	}
}


/**
 * Prints the pull register pin state.
 * 
 * @param[in] fd - output file descriptor
 * @param[in] val - value of the pin
 * @param[in] user - unused
 */
static void printPul(FILE * fd, const uint32_t val, const char * user) {
	static const char * str[] = {
		"Pull-up/down disabled",
		"Pull-up",
		"Pull-down",
		"Reserved"
	};
	(void)user;
	if (fd == NULL) unreachable();
	if (likely(val < 4)) {
		fprintf(fd, "<%s>", str[val]);
	} else {
		fprintf(fd, "<INVALID>");
	}
}


/**
 * Prints a short description to standard error on how to use this
 * command-line tool.
 */
static void printHelp(void) {
	fprintf(stderr,
		"stimud-gpio <action> [<modes>] [<pin#> ...]\n"
		"\n"
		"possible actions:\n"
		"c - clears the output pins\n"
		"f - prints all possible functions of the pins\n"
		"g - returns the value of the input pins\n"
		"h - prints this help\n"
		"m - sets the mode of the pins (see modes below)\n"
		"l - lists the values and configuration the given or all pins\n"
		"s - set the output pins\n"
		"\n"
		"possible modes (multiple possible):\n"
		"- - disabled\n"
		"i - input\n"
		"o - output\n"
		"f - floating\n"
		"u - pull-up\n"
		"d - pull-down\n"
		"\n"
		"pin# can be any number starting at %i for PB0.\n",
		GPIO_PORT_NUMS
	);
}


/**
 * Applies the given action for the passed pin.
 * 
 * @param[in] ptr - GPIO register pointer
 * @param[in] action - action to apply
 * @param[in] modes - action modes if any
 * @param[in] pin - pin number
 */
static void applyAction(volatile tGpioPort * ptr, const char action, const char * modes, const size_t pin) {
	const size_t port = pin / GPIO_PORT_NUMS;
	const size_t num = pin % GPIO_PORT_NUMS;
	const size_t cfgIdx = num / 8;
	const size_t cfgNum = num - (cfgIdx * 8);
	const size_t drvIdx = num / 16;
	const size_t drvNum = num - (drvIdx * 16);
	const size_t pulIdx = num / 16;
	const size_t pulNum = num - (pulIdx * 16);
	if (ptr == NULL) unreachable();
	switch (action) {
	case 'c':
		/* set output value 0 */
		setBits(&(ptr[port].DAT), num, 1, 0);
		break;
	case 'f':
		/* print pin possible functions */
		fprintf(FOUT, "# PIN %u (P%c%u)\n", (unsigned)pin, (int)('A' + port), (unsigned)num);
		for (uint32_t n = 0; n < 8; n++) {
			fprintf(FOUT, "%u: ", (unsigned)n);
			printCfg(FOUT, n, ioFn[pin]);
			fputc('\n', FOUT);
		}
		break;
	case 'g':
		/* print input value (0 or 1) */
		fprintf(FOUT, "%c\n", '0' + getBits(&(ptr[port].DAT), num, 1));
		break;
	case 'm':
		/* change pin mode */
		for (const char * ch = modes; *ch != 0; ch++) {
			switch (*ch) {
			case '-':
				setBits(ptr[port].CFG + cfgIdx, cfgNum * 4, 3, 0x3); /* disable IO */
				break;
			case 'i':
				setBits(ptr[port].CFG + cfgIdx, cfgNum * 4, 3, 0x0); /* set to input mode */
				break;
			case 'o':
				setBits(ptr[port].CFG + cfgIdx, cfgNum * 4, 3, 0x1); /* set to output mode */
				break;
			case 'f':
				setBits(ptr[port].PUL + pulIdx, pulNum * 2, 2, 0x0); /* set floating */
				break;
			case 'u':
				setBits(ptr[port].PUL + pulIdx, pulNum * 2, 2, 0x1); /* enable pull-up */
				break;
			case 'd':
				setBits(ptr[port].PUL + pulIdx, pulNum * 2, 2, 0x2); /* enable pull-down */
				break;
			default:
				continue;
			}
		}
		break;
	case 'l':
		/* list pin value and configuration */
		fprintf(FOUT, "# PIN %u (P%c%u)\n", (unsigned)pin, (int)('A' + port), (unsigned)num);
		printRegisters(FOUT, (const tPrintDesc[]){
			{"CFG", ptr[port].CFG[cfgIdx], cfgNum * 4, 3, printCfg, ioFn[pin]},
			{"DAT", ptr[port].DAT, num, 1, NULL, NULL},
			{"DRV", ptr[port].DRV[drvIdx], drvNum * 2, 2, printDrv, NULL},
			{"PUL", ptr[port].PUL[pulIdx], pulNum * 2, 2, printPul, NULL},
			{NULL}
		});
		break;
	case 's':
		/* set output value 1 */
		setBits(&(ptr[port].DAT), num, 1, 1);
		break;
	default:
		unreachable();
		break;
	}
}


/**
 * Main entry point.
 * 
 * @param[in] argc - number of command-line arguments given 
 * @param[in,out] args - array of given command-line arguments
 * @return exit code
 */
int main(int argc, char ** args) {
	if (unlikely(argc < 2 || args[1][0] == 0 || args[1][1] != 0 || args[1][0] == 'h' || strchr("cfghmls", args[1][0]) == NULL)) {
		printHelp();
		return EXIT_FAILURE;
	}
	
	const char action = args[1][0];
	const char * modes = (action == 'm') ? args[2] : NULL;
	int pinIdx = (action == 'm') ? 3 : 2;
	const size_t pageSize = sysconf(_SC_PAGESIZE);
	const int fd = open("/dev/mem" , O_RDWR | O_SYNC);
	void * mappedAddr = NULL;
	volatile tGpioPort * gpio = NULL;
	int res = EXIT_FAILURE;
	
	size_t pages = 1;
	while ((pages * pageSize) < ((GPIO_PORT_BASE & (pageSize - 1)) + (GPIO_PORT_SIZE * GPIO_PORT_COUNT))) pages++;
	
	/* open memory */
	if (unlikely(fd < 0)) {
		fprintf(stderr, "Error: Failed to open /dev/mem. %s.\n", strerror(errno));
		goto onError;
	}
	
	/* map physical memory region of GPIO registers into user space */
	do {
		errno = 0;
		/* note: we can only request memory pages here (i.e. aligned to and a multiple of it) */
		mappedAddr = mmap(NULL, pages * pageSize, PROT_READ | PROT_WRITE, MAP_SHARED, fd, GPIO_PORT_BASE & ~(pageSize - 1));
	} while (unlikely(mappedAddr == MAP_FAILED && errno == EAGAIN));
	if (unlikely(mappedAddr == MAP_FAILED)) {
		fprintf(stderr, "Error: Failed to map GPIO memory region into user space. %s.\n", strerror(errno));
		goto onError;
	}
	gpio = (volatile tGpioPort *)((uint8_t *)mappedAddr + (GPIO_PORT_BASE & (pageSize - 1)));
	
	/* check conflicting modes */
	if (action == 'm') {
		enum {M_IO = 1, M_PULL = 2};
		int mSet = 0;
		for (const char * ch = modes; *ch != 0; ch++) {
			int m = 0;
			switch (*ch) {
			case '-':
				m = M_IO | M_PULL;
				break;
			case 'i':
			case 'o':
				m = M_IO;
				break;
			case 'f':
			case 'u':
			case 'd':
				m = M_PULL;
				break;
			default:
				fprintf(stderr, "Warning: Ignoring invalid mode '%c'.\n", *ch);
				continue;
			}
			if (unlikely((mSet & m) != 0)) {
				fprintf(stderr, "Error: Mode '%c' conflicts with another mode.\n", *ch);
				goto onError;
			}
			mSet |= m;
		}
		if (unlikely(mSet == 0)) goto onSuccess; /* nothing to set */
	}
	
	/* apply action */
	if (unlikely(argc == 2 && action == 'l')) {
		/* list the values and configuration of all pins */
		for (size_t pin = 0; pin < (GPIO_PORT_COUNT * GPIO_PORT_NUMS); pin++) {
			if (isValidPin(pin) == 0) continue;
			applyAction(gpio, action, modes, pin);
		}
	} else {
		/* apply action for each given pin */
		char * endPtr;
		size_t pin;
		for (; pinIdx < argc; pinIdx++) {
			if (args[pinIdx][0] == 'P' && args[pinIdx][1] >= 'A' && args[pinIdx][1] < ('A' + GPIO_PORT_COUNT)) {
				/* parse pin given like PG1 */
				const size_t port = (size_t)(args[pinIdx][1] - 'A');
				const size_t num = (size_t)strtoul(args[pinIdx] + 2, &endPtr, 10);
				pin = (port * GPIO_PORT_NUMS) + num;
				if (unlikely(endPtr == NULL || *endPtr != 0 || isValidPin(pin) == 0)) {
					fprintf(stderr, "Warning: Ignoring invalid pin number %s.\n", args[pinIdx]);
					continue;
				}
			} else {
				/* parse pin given as number */
				pin = (size_t)strtoul(args[pinIdx], &endPtr, 10);
				if (unlikely(endPtr == NULL || *endPtr != 0 || isValidPin(pin) == 0)) {
					fprintf(stderr, "Warning: Ignoring invalid pin number %s.\n", args[pinIdx]);
					continue;
				}
			}
			applyAction(gpio, action, modes, pin);
		}
	}
	
onSuccess:
	res = EXIT_SUCCESS;
onError:
	/* close open handles */
	if (likely(mappedAddr != NULL)) munmap(mappedAddr, pages * pageSize);
	if (likely(fd >= 0)) close(fd);
	return res;
}
